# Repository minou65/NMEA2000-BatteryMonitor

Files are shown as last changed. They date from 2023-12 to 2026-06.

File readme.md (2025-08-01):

# NMEA Battery monitor

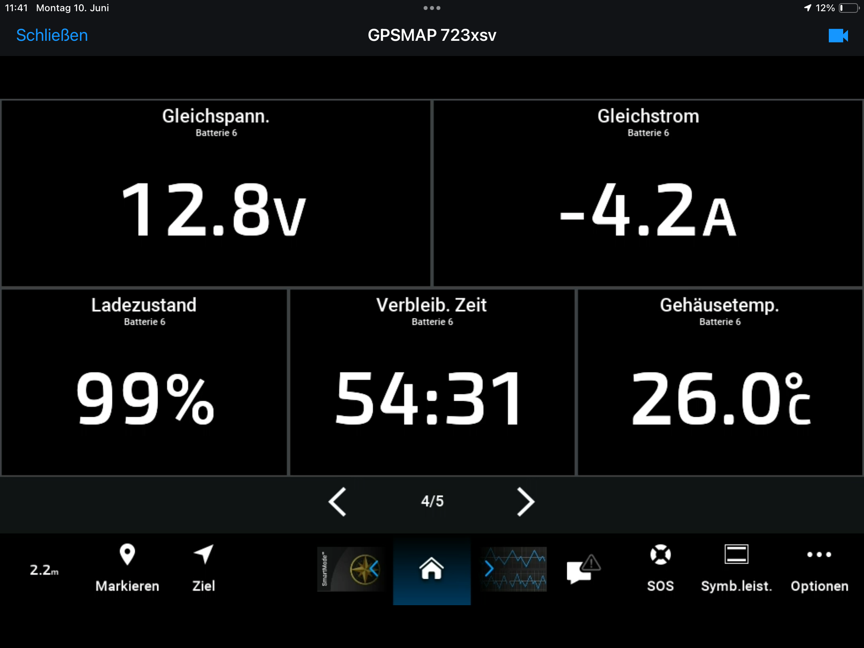
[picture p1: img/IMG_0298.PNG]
garmin


## Table of contents
- [NMEA Battery monitor](#nmea-battery-monitor)
	- [Table of contents](#table-of-contents)
	- [Description](#description)
	- [Disclaimer](#disclaimer)
	- [Schema](#schema)
	- [NMEA 2000](#nmea-2000)
	- [Librarys](#librarys)
	- [Part list](#part-list)
		- [Shunt housing](#shunt-housing)
	- [Running values](#running-values)
		- [Battery voltage](#battery-voltage)
		- [Current](#current)
		- [Avg current](#avg-current)
		- [State of charge (Soc)](#state-of-charge-soc)
		- [Time to go (Ttg)](#time-to-go-ttg)
		- [Battery full](#battery-full)
		- [Temperature](#temperature)
	- [Statistics](#statistics)
	- [Configuration](#configuration)
		- [System configuration](#system-configuration)
			- [Thing name](#thing-name)
			- [AP password](#ap-password)
			- [WiFi SSID](#wifi-ssid)
			- [WiFi password](#wifi-password)
			- [start AP only at boot sequence](#start-ap-only-at-boot-sequence)
			- [AP offline mode after (minutes)](#ap-offline-mode-after-minutes)
		- [NEMA configuration](#nema-configuration)
			- [Instance](#instance)
			- [SID](#sid)
		- [Shunt settings](#shunt-settings)
			- [Shunt resistance \[Ω\] __\*__](#shunt-resistance-ω-)
			- [Expected max current \[A\] __\*__](#expected-max-current-a-)
			- [Voltage calibration factor](#voltage-calibration-factor)
			- [Current calibration factor](#current-calibration-factor)
		- [Battery](#battery)
			- [Type __\*__](#type-)
			- [Voltage __\*__](#voltage-)
			- [Chemistry __\*__](#chemistry-)
			- [Capacity __\*__](#capacity-)
			- [charge efficiency \[%\]](#charge-efficiency-)
			- [Minimum SOC \[%\]](#minimum-soc-)
			- [Replacement date](#replacement-date)
			- [Manufacturer](#manufacturer)
		- [Battery full detection](#battery-full-detection)
			- [Voltage when full \[V\] __\*__](#voltage-when-full-v-)
			- [Tail current \[A\] __\*__](#tail-current-a-)
			- [Delay before full \[s\] __\*__](#delay-before-full-s-)
			- [Current threshold](#current-threshold)
			- [Statistics Page](#statistics-page)
	- [Username and password](#username-and-password)
	- [Default IP address](#default-ip-address)
	- [Firmware Update](#firmware-update)
	- [Blinking codes](#blinking-codes)
	- [Reset](#reset)

## Description
The INA226 is a versatile current and power monitor chip that can be used to create a battery monitor. It measures both voltage and current, taking into account the direction of current flow (whether it’s from or to the battery). Based on the configured ampere-hours (Ah), current, and voltage, it calculates the battery's state of charge.

Here are some key details about the INA226:
- Voltage Measurement Range: 0V to 36V DC
- Shunt Voltage Range (for current measurement): ±82mV
- The INA226 can handle shunt voltages as low as 60mV and as high as 82mV, depending on the current and the shunt resistor used

The INA226 should be connected to the shunt so that charges going into the battery are positive and those coming out of the battery are negative.

 The system communicates via the NMEA 2000 protocol, sending temperature values and alarms as NMEA 2000 messages over an NMEA bus. Configuration is done through a web interface, and real-time values can be viewed on a website. Additionally, there's a link on the configuration page for convenient firmware updates.

 ## Disclaimer
 | | |
 |-|-----------------|
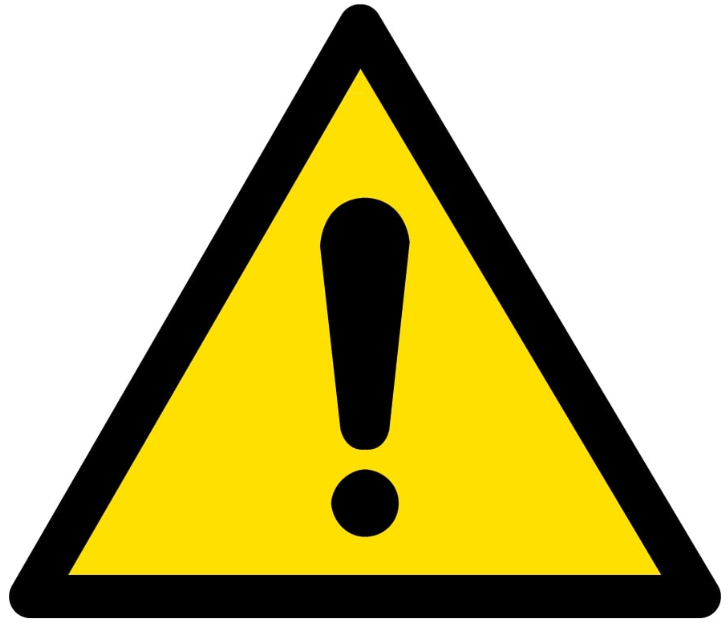
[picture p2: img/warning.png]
warning
 |  | Always use a fuse in the + line from the battery to the sensor!! |
 | warning | Be careful when using metal tools in the vicinity of batteries. Dropping a metal tool onto a battery might cause a short circuit and possibly an explosion. |

## Schema
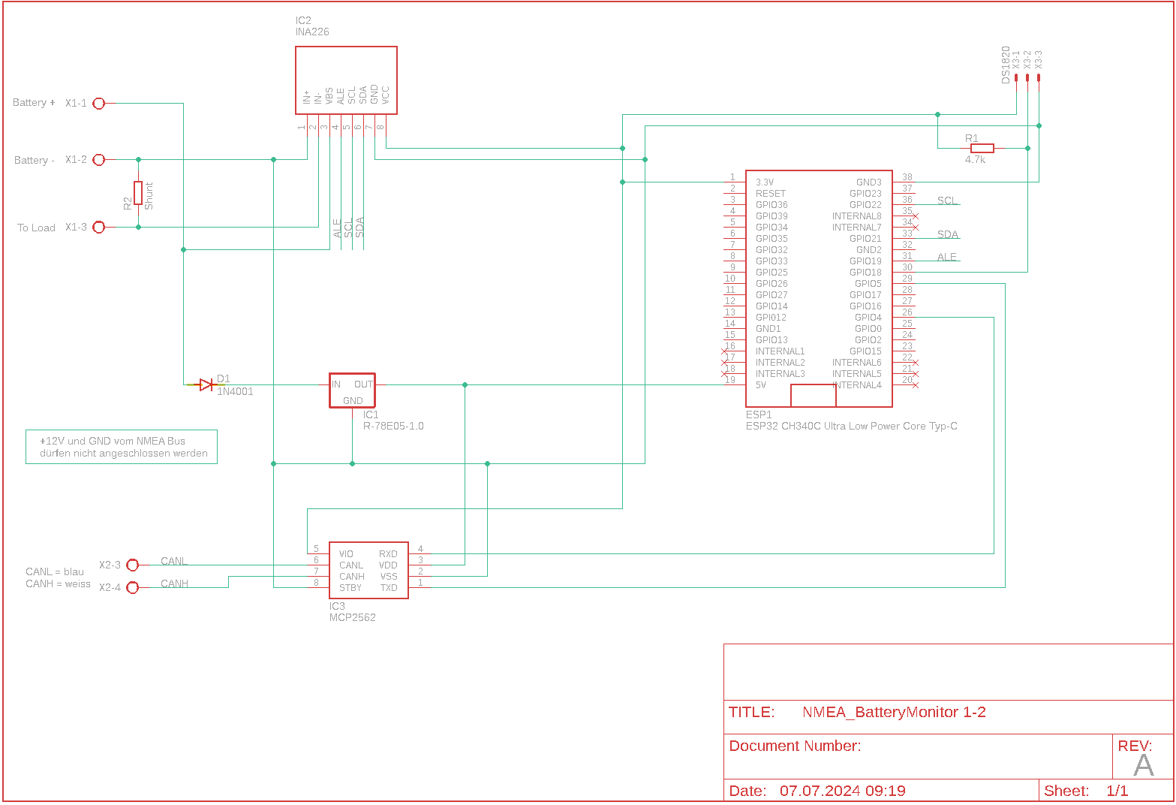
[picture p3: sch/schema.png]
schema


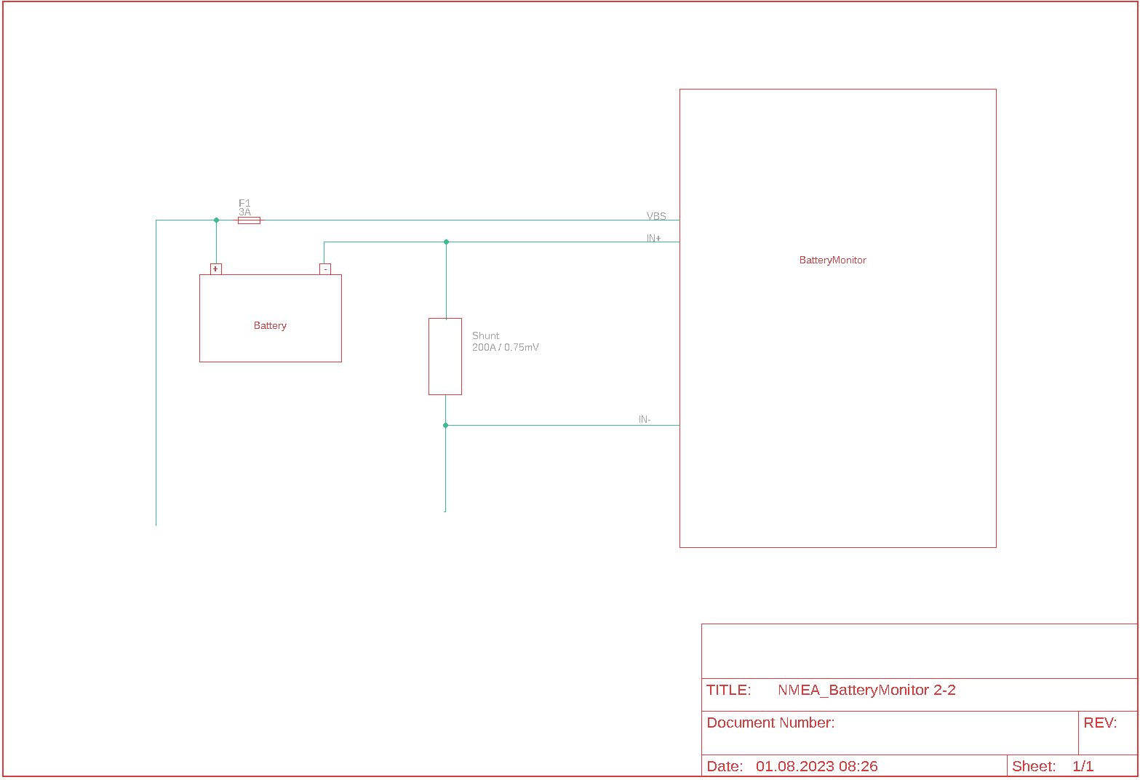
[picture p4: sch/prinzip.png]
pricip schema


## NMEA 2000
The following PGN's will be send
- 127506
- 127508
- 127513

## Librarys 

The Software has been created using Visual Studio with the addon Visual Micro. In order to build it you also need some libraries.

- Wire
- [OneWire (2.3.7)](https://github.com/PaulStoffregen/OneWire)
- [DallasTemperature (3.9.0)](https://github.com/milesburton/Arduino-Temperature-Control-Library)
- [NMEA2000](https://github.com/ttlappalainen/NMEA2000)
- [NMEA2000_ESP32](https://github.com/ttlappalainen/NMEA2000_esp32)
- [AsyncTCP (3.2.6) __*__](https://github.com/mathieucarbou/AsyncTCP)
- [ESPAsyncWebServer (3.3.12) __*__](https://github.com/mathieucarbou/ESPAsyncWebServer)
- [WebSerial (2.0.7) __*__](https://github.com/ayushsharma82/WebSerial)
- [IotWebConf](https://github.com/minou65/IotWebConf)
- [IotWebConfAsync (1.0.2) __*__](https://github.com/minou65/IotWebConfAsync)
- [IotWebRoot](https://github.com/minou65/IotWebRoot)
- [ArduinoJson](https://github.com/bblanchon/ArduinoJson)
- [Preferences](https://github.com/espressif/arduino-esp32/tree/master/libraries/Preferences) (ESP32 built-in)
- [WiFi](https://github.com/espressif/arduino-esp32/tree/master/libraries/WiFi) (ESP32 built-in)
- [Update](https://github.com/espressif/arduino-esp32/tree/master/libraries/Update) (ESP32 built-in)

__*__ new version and/or new repo

## Part list
| Part | Value | Supplier |
| --- | --- | --- |
| D1 | 1N4001 | Reichelt |
| ESP1 | ESP32DEVKITV1 | [ebay](https://www.ebay.ch/itm/204191675506?var=504772734176) |
| IC1 | R-78E05-1.0 | Reichelt |
| IC2 | INA226 | [ebay](https://www.ebay.ch/itm/314750066199) |
| IC3 | MCP2562 | Reichelt oder [ebay](https://www.ebay.ch/itm/364610349378) |
| R1 | 4.7k | Reichelt |
| R2 | Shunt | [ebay](https://www.ebay.ch/itm/164378822180?var=463997139291) |
| X1 | AKL 057-03 | Reichelt |
| X2 | AKL 057-02 | Reichelt |
| X3 | PSS 254/3G | Reichelt |

__Before you can use the sensor board you have to remove the shunt resistor soldered to that board and instead use a bigger shunt, e.g. a 100A/75mV.__

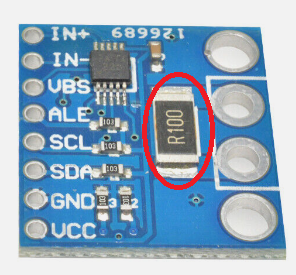
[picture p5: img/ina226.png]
ina226


You also need a __shunt__, since the small resistor on the board (__dont forget to remove it!__) will not survive the high currents.
There are plenty of options out there. Make sure that you select a resistor appropriate for the currents you expect. I'm using a 100A/75mV shunt.

If you have a 48V System, be aware of the fact that the INA226 does only support voltages up to 36V (40V max). You need a voltage divider to make shure your sensor is not destroyed. 
The code assumes that you use a __470KOhm and a 1MOhm__ resistor, measuring across the 1MOhm towards GND. `( + --470K-- --1M -- GND )` The smaller you choose the small resistor in comparison to the bigger one, the more accurate the measurement will be.

### Shunt housing
In the stl folder you will find a housing for the shunt.

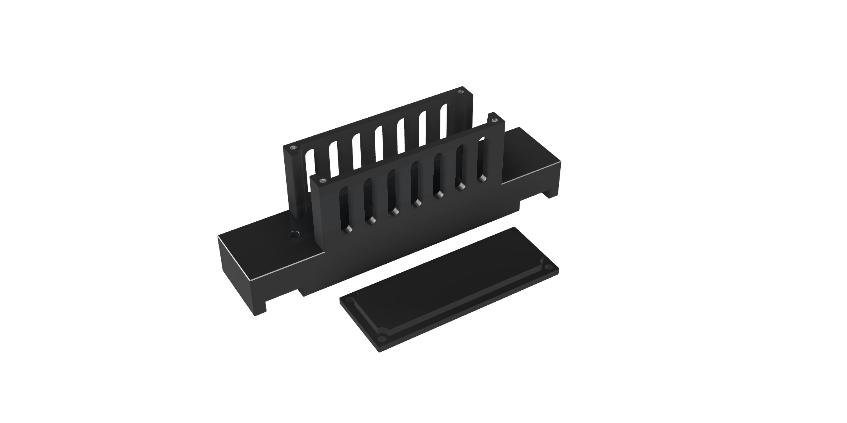
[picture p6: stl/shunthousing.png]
housing


## Running values
### Battery voltage

### Current
Current in amperes flowing through the shunt. If the current is positiv, the battery is being charged. If it is negative, the battery is being discharged.
See [Current calibration factor](#current-calibration-factor) for more information.

### Avg current
The average current consumption in the last 60 seconds.

### State of charge (Soc)
Shows the charge level of the battery. This is calculated based on the capacity and the Ah consumed and is an estimate based on the current consumption.

If no shunt is used and the current calibration factor is set to 0, the following table is used to calculate the Soc

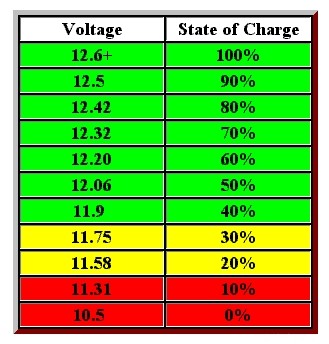
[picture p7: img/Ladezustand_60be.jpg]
ladezustand


### Time to go (Ttg)
If the time is 00:00, then the battery is charging. Otherwise, it will display an estimate in hours and minutes of how long, based on the current consumption, it will take until the battery is empty.

### Battery full
true or false

### Temperature

## Statistics

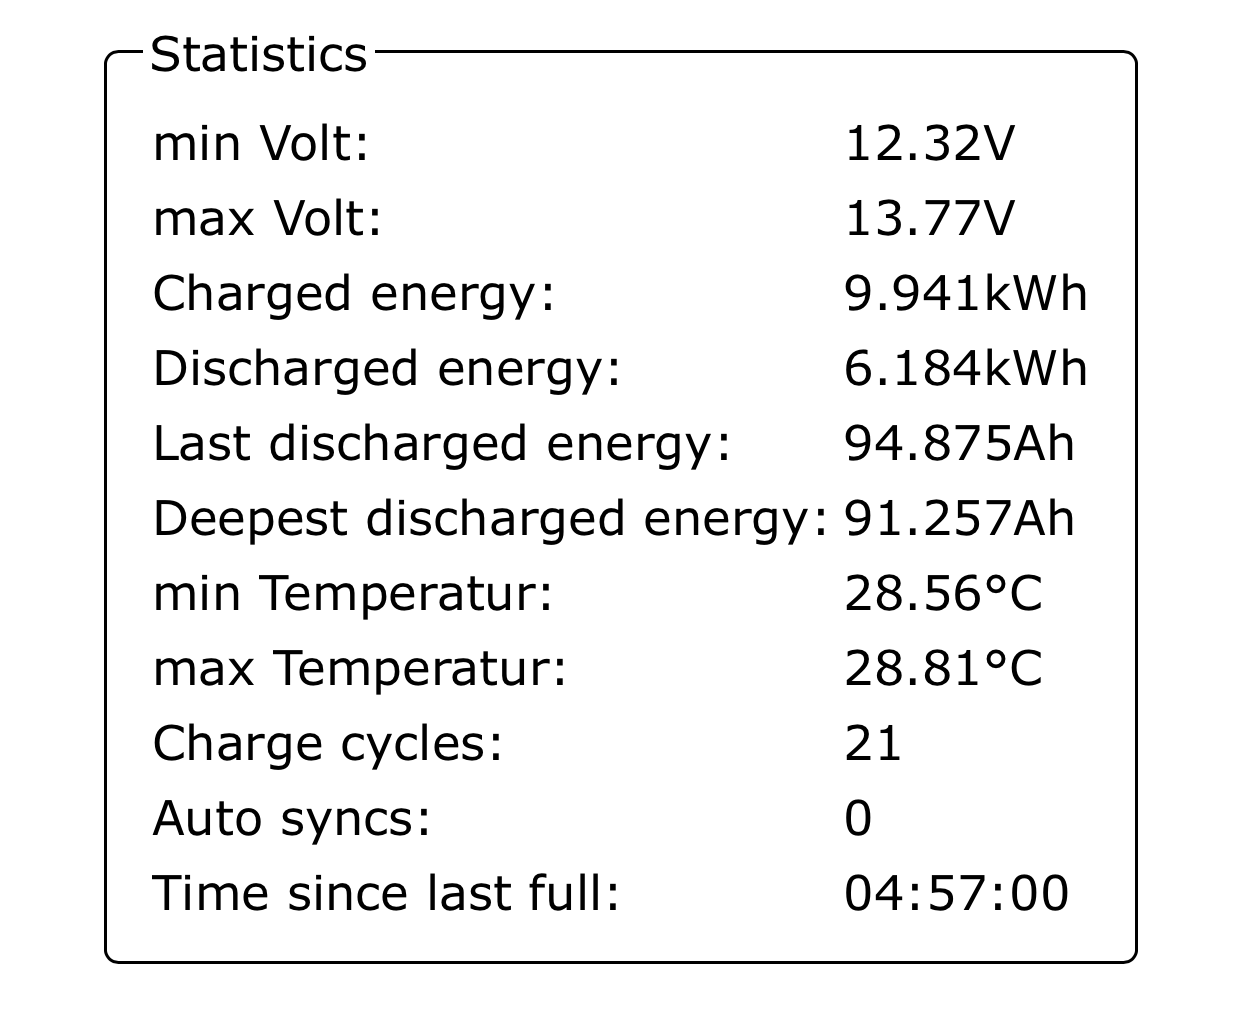
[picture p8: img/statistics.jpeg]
statistics


## Configuration
After the first boot, there are some values needs to be set up.
These items are maked with __*__ (star) in the list below.

### System configuration

#### Thing name
Please change the name of the device to a name you think describes it the most. It is advised to incorporate a location here in case you are planning to set up multiple devices in the same area. You should only use english letters, and the "_" underscore character. Thus, must not use Space, dots, etc. E.g. `main_cabin` __*__

#### AP password
This password is used, when you want to access the device later on. You must provide a password with at least 8, at most 32 characters. You are free to use any characters, further more you are encouraged to pick a password at least 12 characters long containing at least 3 character classes. __*__

#### WiFi SSID
The name of the WiFi network you want the device to connect to. __*__

#### WiFi password
The password of the network above. Note, that unsecured passwords are not supported in your protection. __*__

#### start AP only at boot sequence
This checkbox, when selected, ensures that the Access Point (AP) is initiated only after the system's boot sequence for the time set in the Startup delay. This can be useful for optimizing system performance and security by preventing the AP from starting at other times, which could potentially lead to unauthorized access or unnecessary resource consumption.

The difference to the setting AP offline mode is that after a successful connection to a WiFi, if the connection is lost, it will not fall back to AP mode.

#### AP offline mode after (minutes)
If you don’t plan to connect the sensor to a WiFi network, you don’t need to configure the two options above. If you want to disable the WiFi after a certain time, you can use this option. Specify how long the WiFi should remain enabled after turning on the sensor. Valid values are from 0 to 30 minutes. A value of 0 means that WiFi is always enabled.

### NEMA configuration
#### Instance
This should be unique at least on one device. May be best to have it unique over all devices sending this PGN. A total of 5 instances are occupied by the device, starting with the number set here. __*__

#### SID
Sequence identifier. In most cases you can use just 255 for SID. The sequence identifier field is used to tie different PGNs data together to same sampling or calculation time.

### Shunt settings
#### Shunt resistance [Ω] __*__
```
R = U / I

U in V
I in A
R in Ohm
```

Assuming a voltage of 75 mV at nominal current, the resulting resistance in ohms will be as follows:

| Shunt Current | Resistance in Ohm | Remarks |
| --- | --- | --- |
| 2 | 100 | Original resistor on the board. |
| 50A | 1.500 |
| 100A | 0.750 |
| 200A | 0.375 |
| 300A | 0.250 |

#### Expected max current [A] __*__
Maximum current that may flow through the shunt

#### Voltage calibration factor
Use a multimeter to measure the voltage on the battery. The measured voltage divided by the voltage displayed by the battery monitor gives the factor that you enter here.

#### Current calibration factor
Use a multimeter to measure the current at the shunt. The measured current, divided by the current displayed by the battery monitor, gives the factor that you need to enter here.

Normally a positive current means that the battery is being charged, a negative current means that it is being discharged. If this is the other way round due to incorrect installation of the shunt, the current can be "reversed" by a negative factor.

If this value is set to 0, no current will be measured. This can be useful if no shunt is installed, such as in a starter battery where only voltage and temperature need to be monitored. See also [State of charge (Soc)](#state-of-charge-soc).

### Battery
#### Type __*__
one of the following
- flooded
- gel
- AGM

#### Voltage __*__
- 6V
- 12V
- 24V
- 32V
- 62V
- 42V
- 48V

Please note that the sensor is built for a maximum voltage of 40V without any special measures!

#### Chemistry __*__
- lead acid
- LiIon
- NiCad
- NiMh

#### Capacity __*__
This parameter is used to tell the battery monitor how big the battery is.

The setting is the battery capacity in Amp-hours (Ah).

#### charge efficiency [%] 
The "Charge Efficiency Factor" compensates for the capacity (Ah) losses during charging. A setting of 100% means that there are no losses.
A charge efficiency of 95% means that 10Ah must be transferred to the battery to get 9.5Ah actually stored in the battery. The charge efficiency of a 
battery depends on battery type, age and usage. The battery monitor takes this phenomenon into account with the charge efficiency factor.

The charge efficiency of a lead acid battery is almost 100% as long as no gas generation takes place. Gassing means that part of the charge current 
is not transformed into chemical energy, which is stored in the plates of the battery, but is used to decompose water into oxygen and hydrogen 
gas (highly explosive!). The energy stored in the plates can be retrieved during the next discharge, whereas the energy used to decompose water is lost. 
Gassing can easily be observed in flooded batteries. Please note that the ‘oxygen only’ end of the charge phase of sealed (VRLA) gel 
and AGM batteries also results in a reduced charge efficiency.

#### Minimum SOC [%]
The minimum SoC is the lowest level of charge that a battery can safely operate at without damaging its cells or reducing its capacity. It is usually expressed as a percentage of the maximum charge. For example, if a battery has a minimum SoC of 10%, it means that it should not be discharged below 10% of its full capacity.

#### Replacement date
The replacement date is the date when the battery was replaced with a new one. It is only for documentation

#### Manufacturer
Manufacturer can be used for documentation

### Battery full detection
#### Voltage when full [V] __*__
The battery voltage must be above this voltage level to consider the battery as fully charged. As soon as the battery monitor detects that the 
voltage of the battery has reached this "charged voltage" parameter and the current has dropped below the "tail current" parameter for a certain 
amount of time, the battery monitor will set the state of charge to 100%.

The following table can help set the correct value

| Type | fully charged |
| --- | --- |
| 12V lead acid | 12.85V |
| 12V AGM | 12.85V |
| 12V LiIon | 12.65V |

#### Tail current [A] __*__
The battery is considered as fully charged once the charge current has dropped to less than this "Tail current" parameter. 
The "Tail current" parameter is expressed as a percentage of the battery capacity.

Note that some battery chargers stop charging when the current drops below a set threshold. In these cases, the tail current must be set 
higher than this threshold.

As soon as the battery monitor detects that the voltage of the battery has reached the set "Charged voltage" parameter and the current has 
dropped below this "Tail current" parameter for a certain amount of time, the battery monitor will set the state of charge to 100%.

#### Delay before full [s] __*__
This is the time the "Voltage when full [V]" parameter and the "Tail current [A]" parameter must be met in order to consider the battery fully charged.

#### Current threshold
When the current measured falls below the "Current threshold" parameter it will be considered zero. The "Current threshold" is used to cancel out very small currents that can negatively affect the long-term state of charge readout in noisy environments. For example, if the actual long-term current is 0.0A and, due to injected noise or small offsets, the battery monitor measures ­0.05A the battery monitor might, in the long term, incorrectly indicate that the battery is empty or will need to be recharged. When the current threshold in this example is set to 0.1A, the battery monitor calculates with 0.0A so that errors are eliminated.

#### Statistics Page

The Statistics page provides detailed information about the performance and status of your device. Here are the key metrics displayed on this page:

- **Min Volt**: Displays the minimum voltage recorded, e.g., 10.5V.
- **Max Volt**: Displays the maximum voltage recorded, e.g., 13.4V.
- **Charged Energy**: Indicates the total energy charged, measured in kWh.
- **Discharged Energy**: Indicates the total energy discharged, measured in kWh.
- **Total Ah Drawn**: Shows the total ampere-hours drawn.
- **Last Discharged Energy**: Displays the energy discharged during the last cycle.
- **Deepest Discharged Energy**: Shows the deepest discharge recorded.
- **Min Temperature**: Displays the minimum temperature recorded.
- **Max Temperature**: Displays the maximum temperature recorded.
- **Charge Cycles**: Indicates the number of charge cycles completed.
- **Auto Syncs**: Shows the number of automatic synchronizations. Auto Syncs occur every time the sensor detects that the battery is full. In this case, the State of Charge (SOC) is set to 100%.
- **Time Since Last Full**: Displays the time elapsed since the battery was last fully charged.

Additionally, there is a **Reset Statistics** button available on this page. Pressing this button will reset all the recorded statistics to their default values. This can be useful for starting fresh measurements or troubleshooting purposes.

These statistics help you monitor the health and performance of your device, ensuring it operates efficiently and effectively.

## Username and password
Username is admin. when not connected to an AP the default password is 123456789.

## Default IP address
When in AP mode, the default IP address is 192.168.4.1

## Firmware Update
To update the firmware, navigate to the Configuration page and click on the Firmware Update link. Follow the on-screen instructions to complete the update process.

## Blinking codes
Previous chapters mentioned blinking patterns, now here is a table summarizing the meaning of the blink codes.

| Blinking Pattern | Meaning |
| --- | --- |
| Rapid blinking <br>(mostly on, interrupted by short off periods) | Entered Access Point mode. This means the device creates its own WiFi network. You can connect to the device with your smartphone or WiFi capable computer. |
| Alternating on/off blinking | Trying to connect to the configured WiFi network. |
| Mostly off with occasional short flash | The device is online. |
| Mostly off with occasional long flash | The device is in offline mode |

## Reset
When CONFIG_PIN is pulled to ground on startup, the Thing will use the initial
password to buld an AP. (E.g. in case of lost password)

Reset pin is GPIO 13

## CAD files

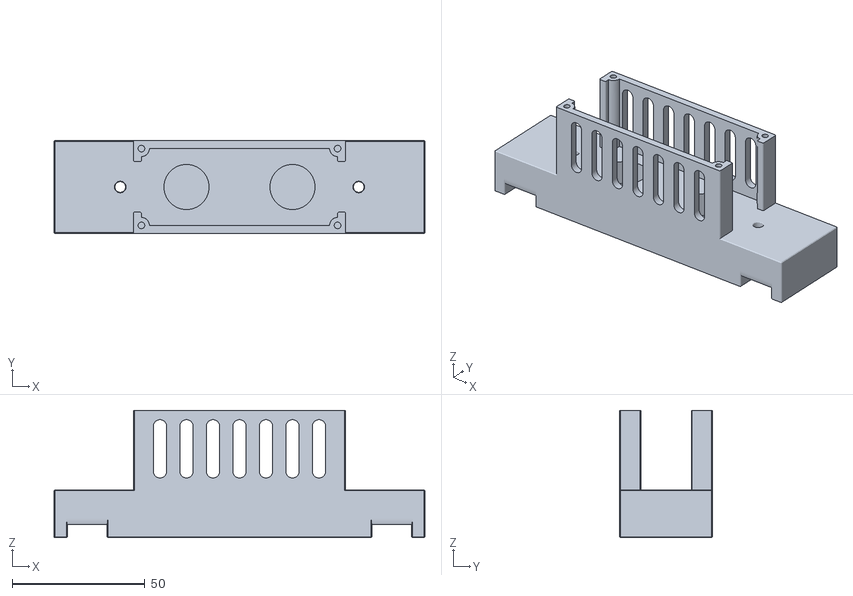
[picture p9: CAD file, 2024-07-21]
stl/Shuntgehäuse.stl
140.0 x 35.0 x 48.0

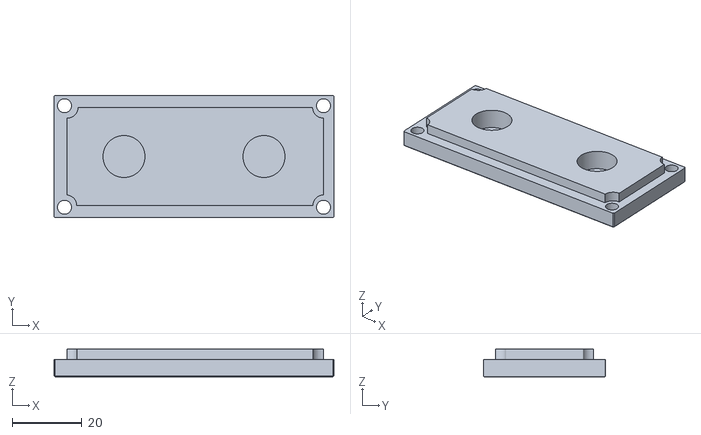
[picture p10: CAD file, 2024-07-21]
stl/Shuntgehäuse - Deckel.stl
80.0 x 35.0 x 8.00

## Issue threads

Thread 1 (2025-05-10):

Disable Shunt when 0Ohm

minou65, 2025-05-10:
Deaktiviere Strommessung wenn Shunt 0Ohm hat

minou65, 2025-05-11:
Kann über den Mulitplikator erreicht werden. Wenn dieser 0 ist wird kein Strom gemessen

Closed 2025-05-11.

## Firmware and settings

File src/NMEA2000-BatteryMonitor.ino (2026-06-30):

#include <Arduino.h>
#include <esp_task_wdt.h>
#include <RebootManager.h>

#include "common.h"
#include "StatusHandling.h"
#include "SensorHandling.h"
#include "webHandling.h"
#include "TemperaturHandling.h"
#include "NMEAHandling.h"
#include "version.h"
#include "neotimer.h"

// Manufacturer's Software version code
char Version[] = VERSION_STR;

// # define IOTWEBCONF_DEBUG_TO_SERIAL true

// Task handle (Core 0 on ESP32)
TaskHandle_t TaskHandle;

void setup() {
    Serial.begin(115200);
    while (!Serial) {
        delay(1);
    }

    Serial.println("\n========================================");
    Serial.println("NMEA2000 battery monitor");
    Serial.println("========================================");
    Serial.printf("Firmware version: %s\n", Version);
    Serial.println("Sensor type: INA226 and DS1820 sensor");
    Serial.printf("INA226 Alert pin:  GPIO_%d\n", INA226_ALERT_PIN);
    Serial.printf("INA226 SCL pin:    GPIO_%d\n", INA226_SCL_PIN);
    Serial.printf("INA226 SDA pin:    GPIO_%d\n", INA226_SDA_PIN);
    Serial.printf("DS1820 Sensor pin: GPIO_%d\n", ONE_WIRE_BUS);
    Serial.println("========================================\n");

#ifdef DISABLE_BROWNOUT_DETECTOR
#include "soc/soc.h"
#include "soc/rtc_cntl_reg.h"
    WRITE_PERI_REG(RTC_CNTL_BROWN_OUT_REG, 0);
    Serial.println("Brownout detector disabled via build flag");
#endif

    RebootManager::begin();
	Serial.printf("Reboot count: %d\n", RebootManager::getRebootCount());
	Serial.printf("Last reboot reason: %s\n", RebootManager::getLastRebootReasonText().c_str());

    Serial.println("\nInitializing WiFi...");
    wifiSetup();

    Serial.println("\nInitializing sensor...");
    sensorInit();
    TemperaturInit();

    Serial.println("\nSetting up NMEA2000...");
    N2kInit();

    xTaskCreatePinnedToCore(
        loop2, /* Function to implement the task */
        "TaskHandle", /* Name of the task */
        16384,  /* Stack size in words */
        NULL,  /* Task input parameter */
        0,  /* Priority of the task */
        &TaskHandle,  /* Task handle. */
        0 /* Core where the task should run */
    );

    esp_task_wdt_add(NULL);

    Serial.println("\n========================================");
    Serial.println("NMEA2000 started");
    Serial.println("Listening for GPS time on NMEA2000 bus");
    Serial.println("Setup complete");
    Serial.println("========================================\n");
}

void loop() {
    if (ParamsChanged) {
        updateINA226Config = true;
        ParamsChanged = false;
    }

    wifiLoop();
    sensorLoop();
    N2Kloop();

    batteryStatus.setTemperatur(GetTemperatur());

    esp_task_wdt_reset();
}

void loop2(void* parameter) {
    esp_task_wdt_add(NULL);
    for (;;) {   // Endless loop
        TemperaturLoop();
        esp_task_wdt_reset();
        vTaskDelay(1000);
    }
}

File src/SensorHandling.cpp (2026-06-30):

#include <Arduino.h>
#include <Wire.h>
#include <WebSerial.h>

#include "common.h"
#include "INA226.h"
#include "INA226EnumToString.h"
#include "sensorHandling.h"
#include "statusHandling.h"
#include "neotimer.h"
#include "BatteryConfig.h"

#define DEBUG_SENSOR_Config
// #define DEBUG_SENSOR

volatile uint16_t alertCounter = 0;
double sampleTime = 0;
bool INA226Initialized = false;
bool updateINA226Config = true;

static INA226 ina(Wire);
Neotimer statisticsTimer = Neotimer(1000);
Neotimer outputTimer = Neotimer(15000);
Neotimer savePreferenceTimer = Neotimer(180 * 60 * 1000); // 3 hours

IRAM_ATTR void alert(void) { ++alertCounter; }

String getCurrentTime() {
    time_t now_ = time(nullptr);
    struct tm* timeInfo_ = localtime(&now_);

    char buffer_[9]; // Puffer für "H:m:s"
    strftime(buffer_, sizeof(buffer_), "%H:%M:%S", timeInfo_);

    return String(buffer_);
}

uint16_t translateConversionTime(ina226_shuntConvTime_t time) {
    uint16_t result_ = 0;
    switch (time) {
        case INA226_BUS_CONV_TIME_140US:
        result_ = 140;
        break;
        case INA226_BUS_CONV_TIME_204US:
        result_ = 204;
        break;
        case INA226_BUS_CONV_TIME_332US:
        result_ = 332;
        break;
        case INA226_BUS_CONV_TIME_588US:
        result_ = 588;
        break;
        case INA226_BUS_CONV_TIME_1100US:
        result_ = 1100;
        break;
        case INA226_BUS_CONV_TIME_2116US:
        result_ = 2116;
        break;
        case INA226_BUS_CONV_TIME_4156US:
        result_ = 4156;
        break;
        case INA226_BUS_CONV_TIME_8244US:
        result_ = 8244;
        break;
        default:
        result_ = 0;
    }
    return result_;
}

uint16_t translateSampleCount(ina226_averages_t value) {
    uint16_t result_ = 0;
    switch (value) {
        case INA226_AVERAGES_1:
        result_ = 1;
        break;
        case INA226_AVERAGES_4:
        result_ = 4;
        break;
        case INA226_AVERAGES_16:
        result_ = 16;
        break;
        case INA226_AVERAGES_64:
        result_ = 64;
        break;
        case INA226_AVERAGES_128:
        result_ = 128;
        break;
        case INA226_AVERAGES_256:
        result_ = 256;
        break;
        case INA226_AVERAGES_512:
        result_ = 512;
        break;
        case INA226_AVERAGES_1024:
        result_ = 1024;
        break;
        default:
        result_ = 0;
    }

  return result_;
}

void checkConfig() {
	Serial.printf("Configuration of INA226\n");
	Serial.printf("    Mode:                  %s\n", INA226EnumTypeToStr(ina.getMode()));
	Serial.printf("    Samples average:       %s\n", INA226EnumTypeToStr(ina.getAverages()));
	Serial.printf("    Bus conversion time:   %s\n", INA226EnumTypeToStr((ina226_busConvTime_t)ina.getBusConversionTime()));
	Serial.printf("    Shunt conversion time: %s\n", INA226EnumTypeToStr(ina.getShuntConversionTime()));
	Serial.printf("    Max possible current:  %.3f A\n", ina.getMaxPossibleCurrent());
	Serial.printf("    Max current:           %.3f A\n", ina.getMaxCurrent());
	Serial.printf("    Max shunt voltage:     %.5f V\n", ina.getMaxShuntVoltage());
	Serial.printf("    Max power:             %.3f W\n", ina.getMaxPower());
    Serial.printf("    Shunt resistance:      %.5f R\n", shuntConfig.ShuntResistance());
    Serial.printf("    Shunt max current:     %i A\n", shuntConfig.MaxCurrent());

}

void setupSensor() {
    // Default INA226 address is 0x40
    INA226Initialized = ina.begin();
	statisticsTimer.start();
    outputTimer.start();
    savePreferenceTimer.start();

    // Check if the connection was successful, stop if not
    if (!INA226Initialized) {
        Serial.println("Connection to sensor failed");
		return;
    }
    // Configure INA226
    ina.configure(INA226_AVERAGES_64, INA226_BUS_CONV_TIME_2116US, INA226_SHUNT_CONV_TIME_2116US, INA226_MODE_SHUNT_BUS_CONT);
    ina.calibrate(shuntConfig.ShuntResistance(), shuntConfig.MaxCurrent());
    ina.enableConversionReadyAlert();

    Serial.printf("calibrate sensor: Shunt resitance = %.5fR, max currenct = %iA\n", shuntConfig.ShuntResistance(), shuntConfig.MaxCurrent());
    batteryStatus.setParameters(
        batteryConfig.Capacity_Ah(), 
        batteryConfig.ChargeEfficiency_Percent(), 
        batteryConfig.MinSoc_Percent(),
        batteryFullConfig.TailCurrent_mA(),
        batteryFullConfig.FullVoltage_mV(), 
        batteryFullConfig.FullDelay_s()
    );

    uint16_t conversionTimeShunt_ = translateConversionTime(ina.getShuntConversionTime());
    uint16_t conversionTimeBus_ = translateConversionTime((ina226_shuntConvTime_t)ina.getBusConversionTime());
    uint16_t samples_ = translateSampleCount(ina.getAverages());

    // This is the time it takes to create a new measurement
    sampleTime = (conversionTimeShunt_ + conversionTimeBus_) * samples_ * 0.000001  ;
}

void sensorInit() {
    Wire.begin(INA226_SDA_PIN, INA226_SCL_PIN); 
    attachInterrupt(digitalPinToInterrupt(INA226_ALERT_PIN), alert, FALLING);

    setupSensor();

    batteryStatus.begin();

	if (!INA226Initialized) {
		return;
	}
}

void updateAhCounter() {
    int count_;
    noInterrupts();
    // If we missed an interrupt, we assume we had the same value all the time.
    count_ = alertCounter;
    alertCounter = 0;
    interrupts();

    //float _shuntVoltage = ina.readShuntVoltage();
    float current_  = ina.readShuntCurrent() * shuntConfig.CurrentCalibrationFactor();
    batteryStatus.updateConsumption(current_, sampleTime, count_);

    //WebSerial.printf("%s : Update Ah counter\n", getCurrentTime());
    //WebSerial.printf("    current: %.2f\n", current_);
    //WebSerial.printf("    voltage: %.2f\n", batteryStatus.voltage());
    //WebSerial.printf("    sampletime: %.2f\n    count: %i\n", sampleTime, count_);

#ifdef DEBUG_SENSOR
    Serial.println(F("Update Ah counter"));

    Serial.printf("current is: %.2f (CurrentCalibrationFactor = %.2f)\n", _current, shuntConfig.CurrentCalibrationFactor());
    Serial.printf("    sampletime: %.2f\n    count: %i\n", sampleTime, _count);
    if(_count > 1) {
        Serial.printf("Overflow %d\n", _count);
		WebSerial.printf("%s : Overflow %d\n", getCurretnTime(),  _count);
    } 
#endif // DEBUG_SENSOR

}
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

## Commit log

2023-08-27 get battery type from array
2023-12-26 BatteryInstance added
2024-01-02 Battery settings added and config version changed
2024-01-02 Battery settings added
2024-01-02 timers changed
2024-01-03 fixed some math errors
    [NMEAHandling.cpp, SensorHandling.cpp, StatusHandling.cpp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]
2024-01-05 fixed read voltage
2024-02-29 new file
    [NMEA_BatteryMonitor 1-2.sch, NMEA_BatteryMonitor 2-2.sch]
2024-05-02 reset pin set
2024-05-18 fix a buffer overflow
    [NMEA2000-BatteryMonitor.ino, webHandling.cpp]
2024-05-18 fix reading bus when not ready
    [NMEA2000-BatteryMonitor.ino, SensorHandling.cpp]
2024-05-19 for not flodingOnwire bud added a delay for reading tem sensor
2024-05-19 Revert "onProgress added for WebSerial outbut"
    This reverts commit d8d793680ea8311a2959ac1391c642516a9c2a07.
    [webHandling.cpp]
2024-05-19 Revert "onProgress added for WebSerial outbut"
    This reverts commit bc469ae8f4175641b22e035b5cf81efb3cb0a5a6.
    [webHandling.cpp]
2024-05-21 read current also when it is below gCurrentThreshold
2024-05-26 fixed TtG calculation from seconds to HH:mm
    [webHandling.cpp]
2024-05-26 fixed some math errors and added some debug infos
    [SensorHandling.cpp]
2024-05-26 initial version
    [NMEA_BatteryMonitor 1-2.sch]
2024-05-30 made thread robust
2024-06-02 some calculation errors and unit errors corrected
    [NMEAHandling.cpp, SensorHandling.cpp, StatusHandling.cpp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]
2024-06-07 checkFull battery improved
2024-06-09 allow negativ values for CalibrationFactor
2024-06-09 pass correct values to the bus
    [NMEAHandling.cpp]
2024-06-09 output every 15s battery status
2024-06-10 error in checkfull fixed
    [StatusHandling.cpp]
2024-06-11 revertet some changes
    [NMEA_BatteryMonitor 1-2.sch]
2024-06-12 fix i temp is -127
    [StatusHandling.cpp]
2024-06-13 linke to main page fixed
    [webHandling.cpp]
2024-07-03 added help for removing resistor on ina226
2024-07-03 added some missing values
    [NMEA_BatteryMonitor 1-2.sch]
2024-07-09 schema updated
    [NMEA_BatteryMonitor 1-2.sch]
2024-07-21 fixed some bugs in writeStats and readStats
    [StatusHandling.cpp]
2024-07-21 updated dimenssions
    [Shuntgehäuse - Deckel.stl, Shuntgehäuse.stl]
2024-08-18 Watchdog timer removed
2024-08-18 fixed some errors in statistics handling
    [StatusHandling.cpp]
2024-10-07 Updated to ESPAsyncWebServer version 3.3.12 and removed dependency on ArduinoJson.
2024-10-11 Fixed bug where redirection to root page doesn’t work after reboot
    [webHandling.cpp]
2024-10-12 use new method AsyncUpdater.isFinished() for rebooting device after firmware updated
    [webHandling.cpp]
2024-10-12 Refactor sensor loop and battery status handling
    - Refactored the sensor loop in SensorHandling.cpp to include a new timer, savePreferenceTimer, which triggers the writing of battery statistics to preferences every 3 hours.
    - Updated the BatteryStatus class in StatusHandling.cpp to include a new member variable, magic, and initialize it with a predefined value.
    - Modified the writeStats() function in StatusHandling.cpp to use Preferences to store the battery statistics in non-volatile memory.
2024-12-18 Fix platform detection in webHandling.cpp for ESP32 and ESP8266
    [webHandling.cpp]
2025-05-04 Remove unused parameters for pressure and humidity sources in NMEAConfig class
2025-05-04 Update shunt resistance parameter to allow lower minimum value
2025-05-04 Fix preprocessor directive for ESP32 platform detection in webHandling.h
2025-05-04 Increase precision of shunt resistance value in JSON response and HTML display
2025-05-19 Add 'Statistics Page' section to README and clarify current calibration instructions
2025-05-19 Refactor WiFi connection handling: remove unused connectAp function and add failure handler
    [webHandling.cpp]
2025-05-29 Increase precision of shunt resistance value in configuration and display
2025-05-30 Increase precision of shunt resistance and voltage display in sensor handling
2025-10-26 fix: add battery mode to JSON response, and streamline HTML response construction
    [webHandling.cpp]
2026-01-09 Refactor library handling and includes
    Added missing library headers (<Wire.h>, <OneWire.h>, <DallasTemperature.h>, <Preferences.h>) to make dependencies explicit and fix compilation issues.
    Unified CAN pin definitions and NMEA2000_CAN initialization in NMEA2000-BatteryMonitor.ino and moved them to the top of the file.
    Removed obsolete or commented‑out code (e.g., watchdog, stack monitoring).
    Reorganized includes in NMEAHandling.cpp/h and centralized tNMEA2000 handling.
    Bumped version to 1.5.1 for improved compatibility and maintainability across development environments.
    Bibliotheksorganisation verbessert, Code aufgeräumt
    Fehlende Bibliotheken in Headern ergänzt (<Wire.h>, <OneWire.h>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
    [INA226.h, NMEA2000-BatteryMonitor.ino, NMEAHandling.cpp]
2026-01-11 Revert "Refactor library handling and includes"
    This reverts commit ac40590587ba705850a5181539441795a9495458.
    [INA226.h, NMEA2000-BatteryMonitor.ino, NMEAHandling.cpp]
2026-04-25 Refactor: update watchdog timer configuration and cleanup
2026-04-25 feat: add logRebootReason function to track reboot count and reason
    [NMEA2000-BatteryMonitor.ino, webHandling.cpp]
2026-04-25 fix: reset watchdog timer in loop2 to prevent system resets
    [NMEA2000-BatteryMonitor.ino]
2026-04-26 feat: enhance reboot logging with detailed reason and count tracking
    [NMEA2000-BatteryMonitor.ino]
2026-05-31 refactor: streamline writeStats and readStats functions for improved clarity and error handling
    [StatusHandling.cpp]
2026-05-31 refactor: replace custom reboot logging with RebootManager for streamlined reboot tracking
    [NMEA2000-BatteryMonitor.ino]
2026-06-24 schema removed
    [NMEA_BatteryMonitor (ESP32_D1_Mini).brd, NMEA_BatteryMonitor (ESP32_D1_Mini).sch]
2026-06-25 fix: correct shunt resistance calibration in setupSensor and sensorLoop functions
    [SensorHandling.cpp]
2026-06-26 fix: update current LSB calculations to use INA226_CURRENT_RANGE for accuracy
    [INA226.h]
2026-06-28 refactor: introduce new configuration classes for battery and shunt settings
2026-06-28 refactor: remove unused battery-related variables from common.h
2026-06-28 refactor: update battery and shunt configuration usage in handleData function
2026-06-30 feat: add BatteryConfig, ShuntConfig, and BatteryFullConfig classes for enhanced battery management
2026-06-30 refactor: enhance board configuration options and improve error handling in common.h
    [common.h]
2026-06-30 refactor: remove hardcoded OneWire bus definition and fix temperature logging reference
2026-06-30 refactor: rename global battery status variable and update calibration factor references
2026-06-30 refactor: streamline sensor handling by removing unused variables and updating configuration references
2026-06-30 refactor: enhance setup logging and improve brownout detector handling
    [NMEA2000-BatteryMonitor.ino]
